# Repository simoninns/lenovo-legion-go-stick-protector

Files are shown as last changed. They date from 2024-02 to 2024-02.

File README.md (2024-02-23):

# Lenovo Legion Go Stick Protector
## Overview
This project provides a 3D printable stick protector for the Lenovo Legion Go.  The protector is a simple clip that secures the thumbsticks to prevent damage.

This project is GPLv3 open-source.

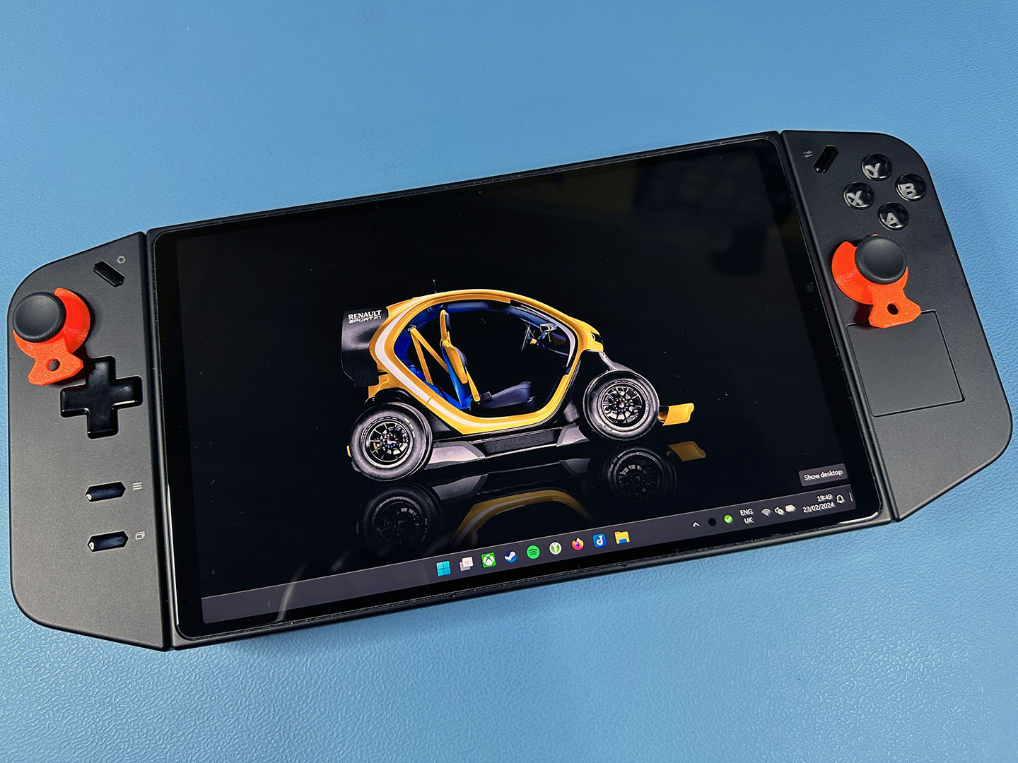
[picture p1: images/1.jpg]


## Printing instructions
The model has been printed and tested on the Prusa MK3S/MMU2S printer using Prusament PETG filament. All parts fit the standard print bed.

### Recommended print settings

Print settings (for Prusa Slicer) are as follows:

* Material: PETG
* Layer: 0.20mm (Quality)
* Infill: 15%
* No supports required

## Author
This project is designed and maintained by Simon Inns.

## Cloning notes
This repo contains the BOSL OpenSCAD library as a sub-module, after you clone this repo use the following command to initialise the sub-modules:

git submodule update --init

# Licensing
## OpenSCAD source files - software license (GPLv3)

    This is free software: you can redistribute it and/or modify
    it under the terms of the GNU General Public License as published by
    the Free Software Foundation, either version 3 of the License, or
    (at your option) any later version.
    
    This program is distributed in the hope that it will be useful,
    but WITHOUT ANY WARRANTY; without even the implied warranty of
    MERCHANTABILITY or FITNESS FOR A PARTICULAR PURPOSE.  See the
    GNU General Public License for more details.
    
    You should have received a copy of the GNU General Public License
    along with this program.  If not, see <http://www.gnu.org/licenses/>.

## Non-source-code media - Creative Commons license (Creative Commons BY-SA 4.0)
Please see the following link for details: https://creativecommons.org/licenses/by-sa/4.0/

You are free to:

Share - copy and redistribute the material in any medium or format
Adapt - remix, transform, and build upon the material
for any purpose, even commercially.

This license is acceptable for Free Cultural Works.

The licensor cannot revoke these freedoms as long as you follow the license terms.

Under the following terms:

Attribution - You must give appropriate credit, provide a link to the license, and indicate if changes were made. You may do so in any reasonable manner, but not in any way that suggests the licensor endorses you or your use.

ShareAlike - If you remix, transform, or build upon the material, you must distribute your contributions under the same license as the original.

No additional restrictions - You may not apply legal terms or technological measures that legally restrict others from doing anything the license permits.

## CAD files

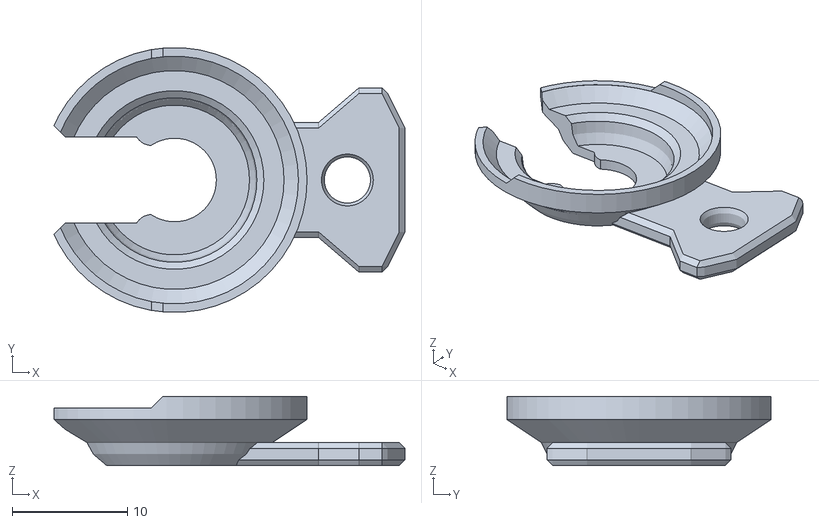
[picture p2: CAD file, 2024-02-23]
stl/protector.stl
30.5 x 23.0 x 6.00

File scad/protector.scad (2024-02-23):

/************************************************************************

    protector.scad
    
    Lenovo Legion Go Stick Protector
    Copyright (C) 2024 Simon Inns
    
    This is free software: you can redistribute it and/or modify
    it under the terms of the GNU General Public License as published by
    the Free Software Foundation, either version 3 of the License, or
    (at your option) any later version.
    
    This program is distributed in the hope that it will be useful,
    but WITHOUT ANY WARRANTY; without even the implied warranty of
    MERCHANTABILITY or FITNESS FOR A PARTICULAR PURPOSE.  See the
    GNU General Public License for more details.
    
    You should have received a copy of the GNU General Public License
    along with this program.  If not, see <http://www.gnu.org/licenses/>.
	
    Email: simon.inns@gmail.com
    
************************************************************************/

include <BOSL/constants.scad>
use <BOSL/transforms.scad>
use <BOSL/shapes.scad>

module render_stick_mockup(toPrint)
{
    if (!toPrint) {
        move([0,0,1]) {
            cyl(h=4, d=7, center=false);

            move([0,0,4]) cyl(h=1, d1=14, d2=16, center=false);
            move([0,0,5]) cyl(h=1.5, d=16, center=false);
            move([0,0,6.5]) cyl(h=1, d1=16, d2=14, center=false);
        }

        move([0,0,0]) cyl(h=1, d1=20, d2=18, center=false);
    }
}

module protector()
{
    difference() {
        union() {
            move([0,0,4]) cyl(h=1, d1=16, d2=14, center=false);
            move([0,0,2]) cyl(h=2, d1=18, d2=16, center=false);
            move([0,0,1]) cyl(h=2, d2=17, d1=23, center=false);
            move([0,0,0]) cyl(h=1, d=23, center=false);

            // Handle
            move([9,0,4]) cuboid([20,10,2], chamfer=0.5);
            hull() {
                move([15,0,4]) cuboid([6,10,2], chamfer=0.5);
                move([17,0,4]) cuboid([3,16,2], chamfer=0.5);
                move([19,0,4]) cuboid([2,10,2], chamfer=0.5);
            }
        }

        // Gap
        difference() {
            union() {
                move([-6,0,2]) cuboid([14,7,10]);
                move([-8,0,2]) cuboid([14,7.5,10]);
            }
            move([-2,4.5,2]) cyl(h=12, d=3);
            move([-2,-4.5,2]) cyl(h=12, d=3);
        }

        // Hollow the centre
        move([0,0,-1]) cyl(h=8, d=7.25, center=false);
        move([0,0,-1]) cyl(h=4, d1=15, d2=14, center=false);
        move([0,0,2.99]) cyl(h=1, d1=14, d2=13, center=false);

        move([0,0,-.75]) cyl(h=2, d1=23, d2=19, center=false);
        cyl(h=4, d=16, chamfer=1);

        // Hole in handle
        move([15,0,4]) cyl(h=4,d=4);
        move([15,0,4+1]) cyl(h=1,d1=4, d2=5);
        move([15,0,4-1]) cyl(h=1,d2=4, d1=5);

        // Trim the front edge
        move([-12,2,0]) zrot(45) cuboid([6,6,5]);
        move([-12,-2,0]) zrot(45) cuboid([6,6,5]);
    }

    difference() {
        move([0,0,-1]) cyl(h=1, d=23, center=false);
        move([0,0,-2]) cyl(h=3, d=21.5, center=false);

        // Trim the front edge
        move([-12,2,0]) zrot(45) cuboid([6,6,5]);
        move([-12,-2,0]) zrot(45) cuboid([6,6,5]);
        move([-11,0,-1.01]) cuboid([20,28,2], chamfer=1);
    }
}   

module render_protector(toPrint)
{
    if (!toPrint) protector();
    else {
        move([0,0,5]) xrot(180) protector();
    }
}

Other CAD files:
scad/main.scad

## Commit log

2024-02-23 Added basic project files and a mock up of the overall thumbstick dimensions
    [main.scad, protector.scad]
2024-02-23 First test piece to check the fit and design
    [main.scad, protector.scad, protector.stl]
2024-02-23 Shape number 2 for testing; now with a better grip for removal
    [protector.scad, protector.stl]
2024-02-23 Third try... slightly deeper shape with wider front slot
    [protector.scad, protector.stl]
2024-02-23 Insertion was lifting the thumbstick too much, so made a modification to the base to make it slide on easier without lifting the stick
    [protector.scad, protector.stl]
